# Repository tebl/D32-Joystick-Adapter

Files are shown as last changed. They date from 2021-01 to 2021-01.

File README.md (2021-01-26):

# D32 Joystick Adapter
I don't have a joystick for any of my Dragon 32s, I actually have two of them - mostly because it's the little welsh machine that thought it could - then it actually did! Often mentioned as a copy of the more successful american, but from what I can see - both of them seem to be a rather straight-forward implementation of a Motorola reference design from the same period. Where I live the computer didn't see much success until after its actual demise, the reason being that they became available at a very low price of *a freaking lot of money* (I was very young at a time, so anything that wasn't, well, a small stack of coins was still a lot to me).

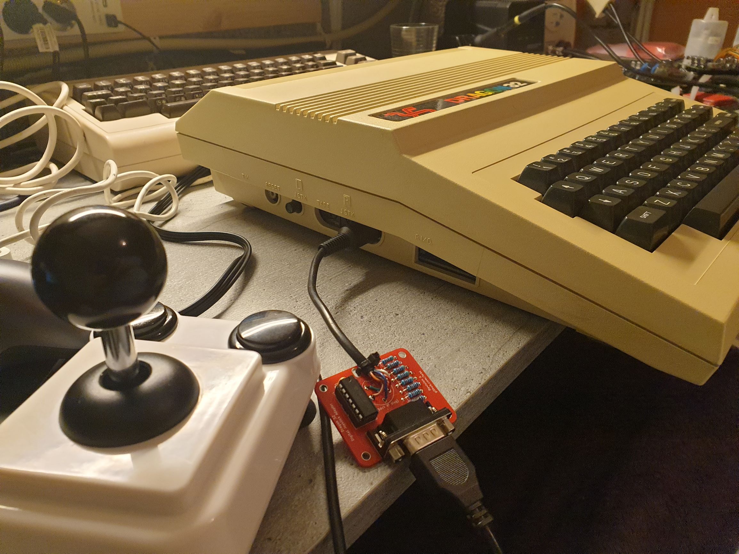
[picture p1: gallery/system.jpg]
Dragon 32


What I don't have however, is a working joystick for any of them. I can't buy one, mainly because according to someone very close to me - I appearantly have enough stuff! So I need to make some more - *all* by myself - *all by myself* (cue the music). Actually, I just searched around for a solution and with the power of Googles search engine at my fingertips - I copied the one from [vrai.net](http://vrai.net/retro/?p=112) and designed a PCB around it.

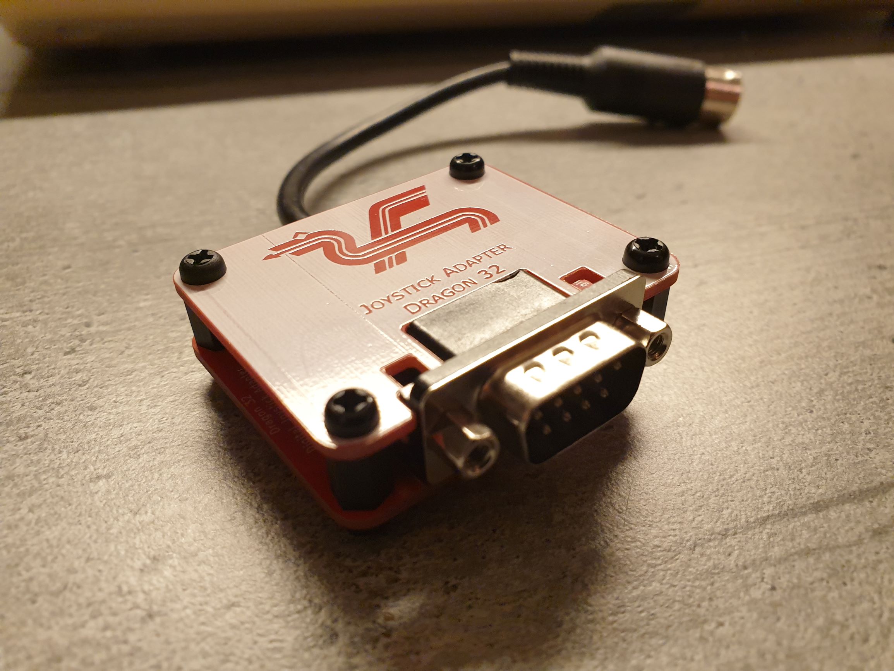
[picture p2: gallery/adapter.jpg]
D32 Joystick Adapter


Anyway - I'm rambling again, but for those just tuning into the workings of my basement laboratory - this project is about making an adapter so standard Atari 9-pin joysticks can be used with the Dragon 32 (also sold as the Tano Dragon in America) and Dragon 64 computers. In theory it could work for the TRS-80 Colour Computer (CoCo), but I don't have one - so until the day someone just gives me one, I can't test it. The finished project, including an optional faceplate can be seen above.

- [1> BOM](#1-bom)
  - [1.1>D32 Joystick Adapter](#11-d32-joystick-adapter)
  - [1.2> D32 Joystick Adapter (Faceplate)](#12-d32-joystick-adapter-faceplate)
- [2> Building the D32 Joystick Adapter](#2-building-the-d32-joystick-adapter)
  - [2.1> Testing it out](#21-testing-it-out)

# 1> BOM
This is the list of parts that you'd need in order to construct a D32 Joystick Adapter, most if not all should be readily available from your friendly neighbourhood electronics store if you should happen to have one available to you. For me, that means ebay since those kind of stores disappeared in the 80s around here - your mileage may wary (and so may the actual friendliness).

I've separated the parts belonging to the actual module into section 1.1, the faceplate is strictly optional and has no active components - I'm just having fun making these, so unless you want one you don't really need the components listed.

## 1.1> D32 Joystick Adapter
| Reference | Item | Count | Order  |
| --- | --- | ----- | --- |
| D32 Joystick Adapter PCB  | Fabricate using Gerber files | 1 | [PCBWay](https://www.pcbway.com/project/shareproject/D32_Joystick_Adapter.html) |
| J1 * | Male 240° connector and 5-core wire | 1 | |
| J2 | Male DB9 right-angle connector | 1 | |
| JP1 ** | 1x2 pin right-angle header and jumper | 1 | |
| R1,R3,R5,R7 | 10k Ohm resistor | 4 | |
| R2,R4,R6,R8 | 47k Ohm resistor | 4 | |
| U1 | CD4066 (DIP-14) | 1 | |

*) Note that this isn't actually a PCB-component, you're supposed to solder the male connector at the other end of the cable. One cheap source of these cables is either purchasing a cheap RS232 cable and cutting off both ends. Use a cable tie as strain relief.

**) This was added so that VCC could be removed from the cable if needed, the *C64 JoyKEY* when including the Arduino drags down the line a bit too much. If you only intend to use regular Atari-style joysticks, feel free to install a piece of wire shorting this instead.

## 1.2> D32 Joystick Adapter (Faceplate)
| Reference | Item | Count | Order  |
| --- | --- | ----- | --- |
| Faceplate A1 (PCB) * | Fabricate using Gerber files | 1 | [PCBWay](https://www.pcbway.com/project/shareproject/D32_Joystick_Adapter__Faceplate_.html) |
| Faceplate A2 (PCB) * | Fabricate using Gerber files | 1 | [PCBWay](https://www.pcbway.com/project/shareproject/D32_Joystick_Adapter__Faceplate_A2_.html) |
| Mounting ** | M3x8mm Nylon Hex standoff | 4 | |
| | M3x6mm nylon screw | 4 | |

*) The A1 and A2 faceplates serve the same function, so you will only need one of them. The A1 faceplate is the Dragon-themed one, A2 has something that should have a larger appeal to our American friends with access to a RadioShack TRS-80 Colour Computer.

**) The suggested nylon standoff should be common values, if you have one of the cheap M3 nylon standoff kits sold on ebay and similar site - feel free to try out whichever works best for you. Keeping within the limits of the kit I'd use the 8mm standoffs, use screws on top and nuts on the underside (cut off the remainder of the screw poking through).

# 2> Building the D32 Joystick Adapter
Building the *D32 Joystick Adapter* should for the most part be an easy affair for most with access to a decent set of tools, burn-proof fingers and a deep-seeded interest in playing games on a Dragon 32 using an Atari-style joystick. Start by reading through the BOM above for a list of all parts required, order what you don't already have tucked into a drawer, chest or the back of the sofa cushions - wherever you keep yours. Everything? Read on for the exciting conclusion to project *"clicky joy with the Dragon 32"*.

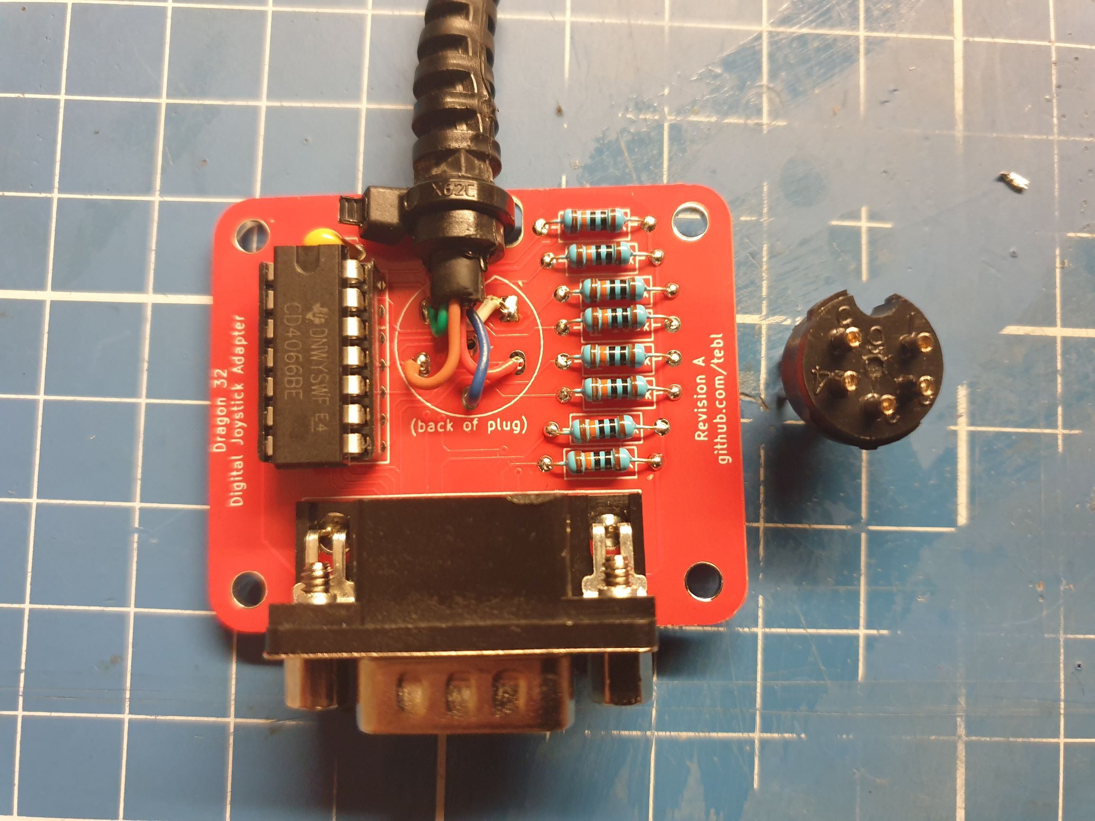
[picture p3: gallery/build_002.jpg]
Build 002


Still here? Excellent.

As pictured above, where I've already done most of the work you can see the finished module. There are many roads to getting there, but the easiest is starting with the resistors - solder them in according to the values printed. Install a 14-pin socket for U1 as everyone hates removing non-functional chips, which is something that's a regularly common affair when ordering things from the non-professional electronic component vendors - they're usually cheaper than regular chips though.

At this point you could install the DB9-connector if you wanted, but I recommend paying attention to the cable install instead - the one with a picture of a DIN-plug on. As long as you've got a cable with enough cores and the ability to tell the wires apart, just pick a colour for each and solder them into place (I'm assuming there isn't a connector on the other end at this point). Use the two larger holes above to zip-tie the cable into place, this ensures that the cable doesn't come undone in the next few days.

Note that the pins on the PCB has been numbered for you, the connector will also have something similar on it. **BEFORE** continuing though, thread the sleeve onto the cable - failiure to do so means you'll have to desolder something tonight (might be either end of the cable). Use the PCB directions on the topside, back of plug view and match the coloured wires to the correct number. Use the numbering on the underside if you're attempting to match it to something that already has the correct connector attached, such as when upcycling the cable from a non-functioning joystick.

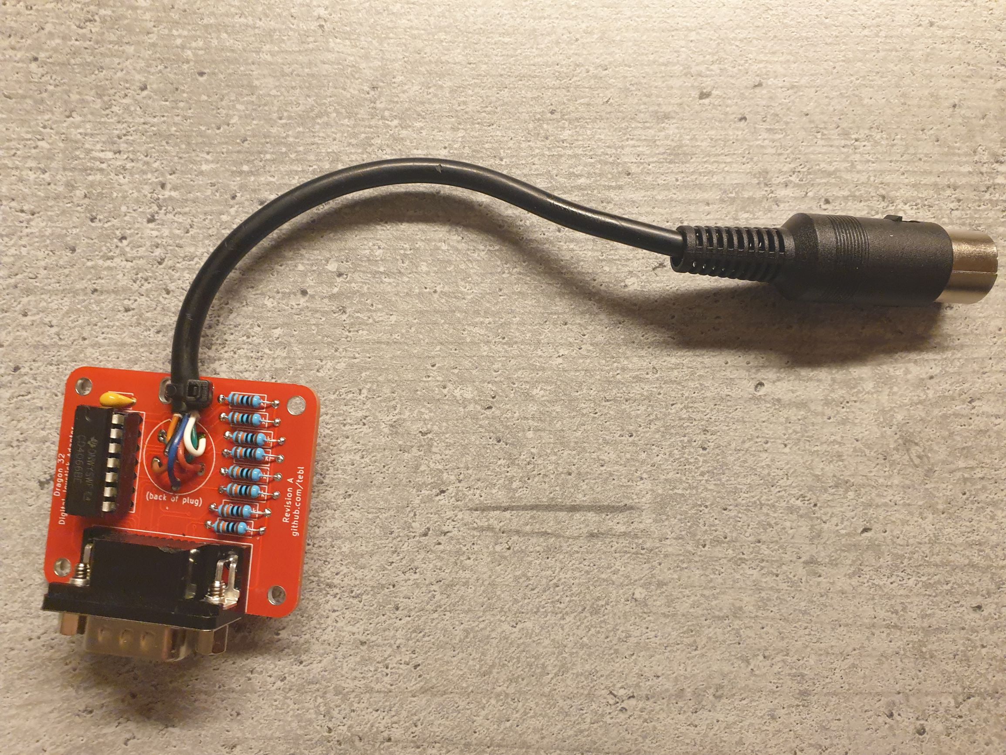
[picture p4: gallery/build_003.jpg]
Build 003


It is my hope that everything'll work out as it should, but before you connect it up to a Dragon 32 I highly recommend that you check for any direct shorts on the power side of things - this is easily done by checking for a lack of contiuity between U1 pins 7 and 14. If you opted for a faceplate, just screw it on using the standoffs listed in the BOM.

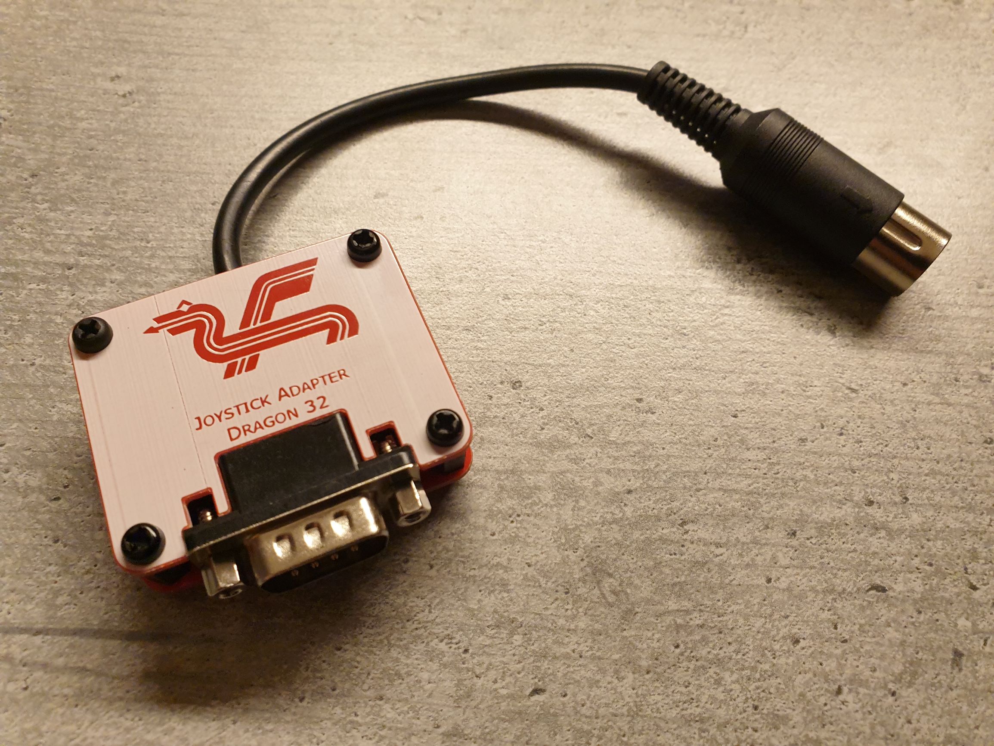
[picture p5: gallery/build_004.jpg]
Build 004


That should be every bit of knowledge I'm able to impart on you this evening, excuse the mistakes and exceptionally bad puns!

## 2.1> Testing it out
Going back to the hope we had in the building section, we now resort to my less than plug-and-pray way of attacking the project. Plug it into the computer, plug an Atari-style joystick into the **right** joystick - because why not do the right one? I got lazy on the script I borrowed from [dragon32forever](https://dragon32forever.wordpress.com/dragon-bytes/joysticks/), that's why. I've included it in the repository under [software](https://github.com/tebl/D32-Joystick-Adapter/tree/main/software), don't bother breaking out a DragonDrive or DragonMMC to load the thing - it is a tiny thing so just type it in.

Here's the next part: RUN

The script should flicker the screen a lot, but between the flickering you should see some numbers for the X- and Y-axis. It should display a number between 0 and 63, when pushing the joystick in all the ways it should jump between the extremes. When not pushing anything it should center somewhere along the middle (around 30).

I found that my [C64 JoyKEY](https://github.com/tebl/C64-JoyKEY) with an Arduino installed pulls the VCC-line too far down (my max value didn't go above 40) so it didn't work properly unless the VCC_EN jumper is removed, the Dragon 32 simply wasn't meant to power an Arduino and a bunch of LEDs via the joystick port - most common Atari-style joysticks with a sensible amount of circuitry should work properly.

Now go play some games, I recommend starting with either *Rommel's Revenge* or *Donkey King* - both worked pretty great for the 5 minutes I spent playing them. That's a pretty good statistic, I just prefer building things these days!

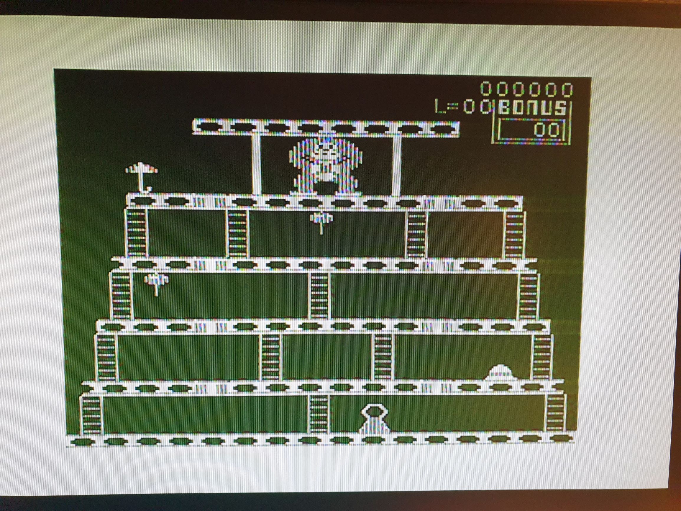
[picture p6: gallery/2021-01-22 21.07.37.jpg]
Donkey King


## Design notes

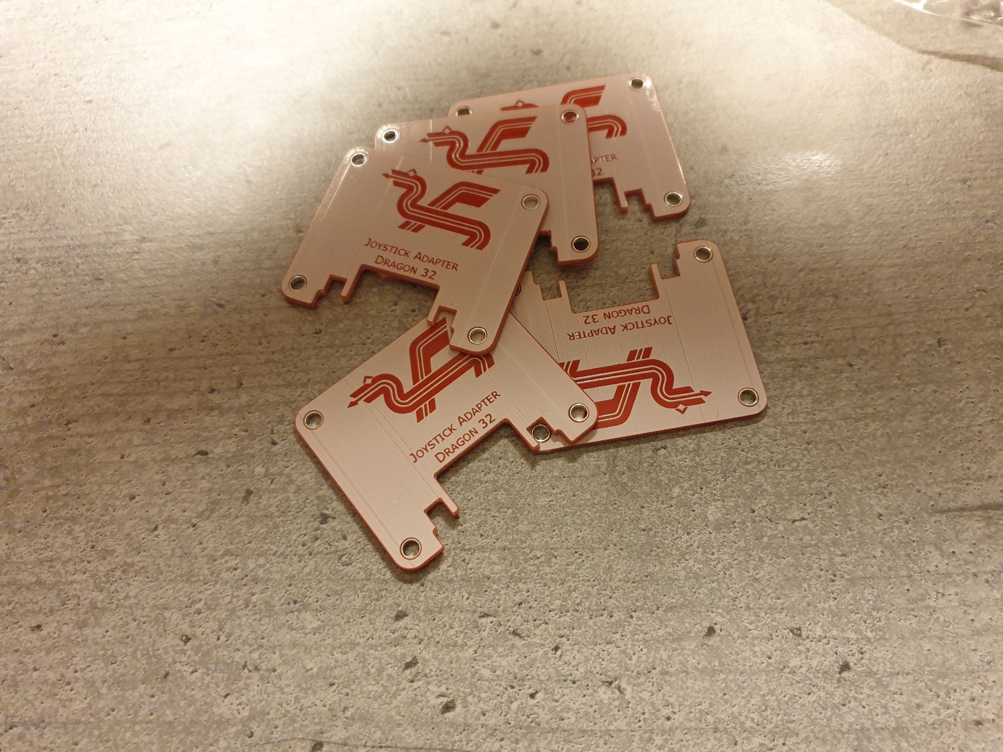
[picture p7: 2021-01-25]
gallery/faceplates.jpg

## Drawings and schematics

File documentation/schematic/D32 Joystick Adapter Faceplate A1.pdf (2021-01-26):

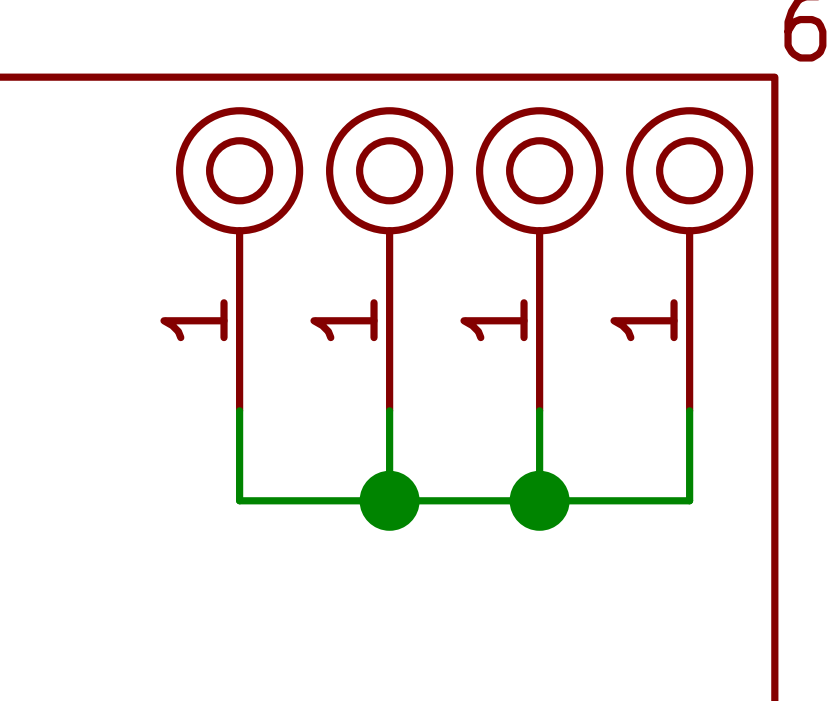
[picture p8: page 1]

File: D32 Joystick Adapter Faceplate A1.sch Sheet: / Faceplate for the D32 Joystick Adapter.

Id: 1/1 Title: D32 Joystick Adapter (Faceplate)

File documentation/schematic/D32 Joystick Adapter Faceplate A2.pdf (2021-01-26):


File: D32 Joystick Adapter Faceplate A2.sch Sheet: / Faceplate for the D32 Joystick Adapter.

Id: 1/1 Title: D32 Joystick Adapter (Faceplate)

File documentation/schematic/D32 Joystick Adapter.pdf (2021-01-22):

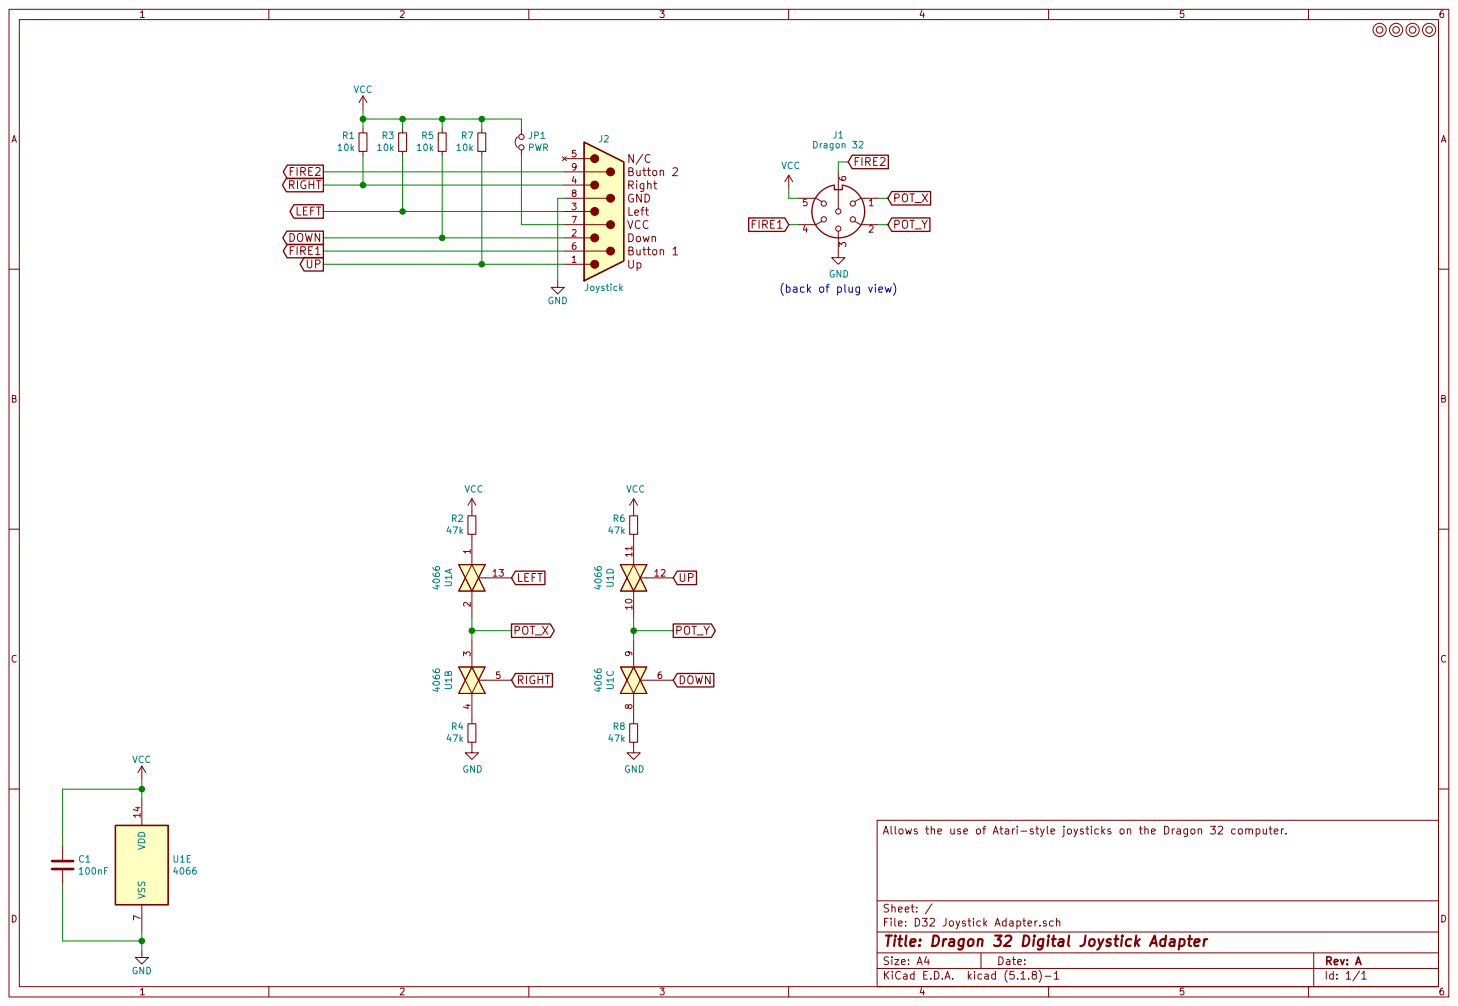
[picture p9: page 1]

(back of plug view)

File: D32 Joystick Adapter.sch Sheet: / Allows the use of Atari-style joysticks on the Dragon 32 computer.

Id: 1/1 Title: Dragon 32 Digital Joystick Adapter

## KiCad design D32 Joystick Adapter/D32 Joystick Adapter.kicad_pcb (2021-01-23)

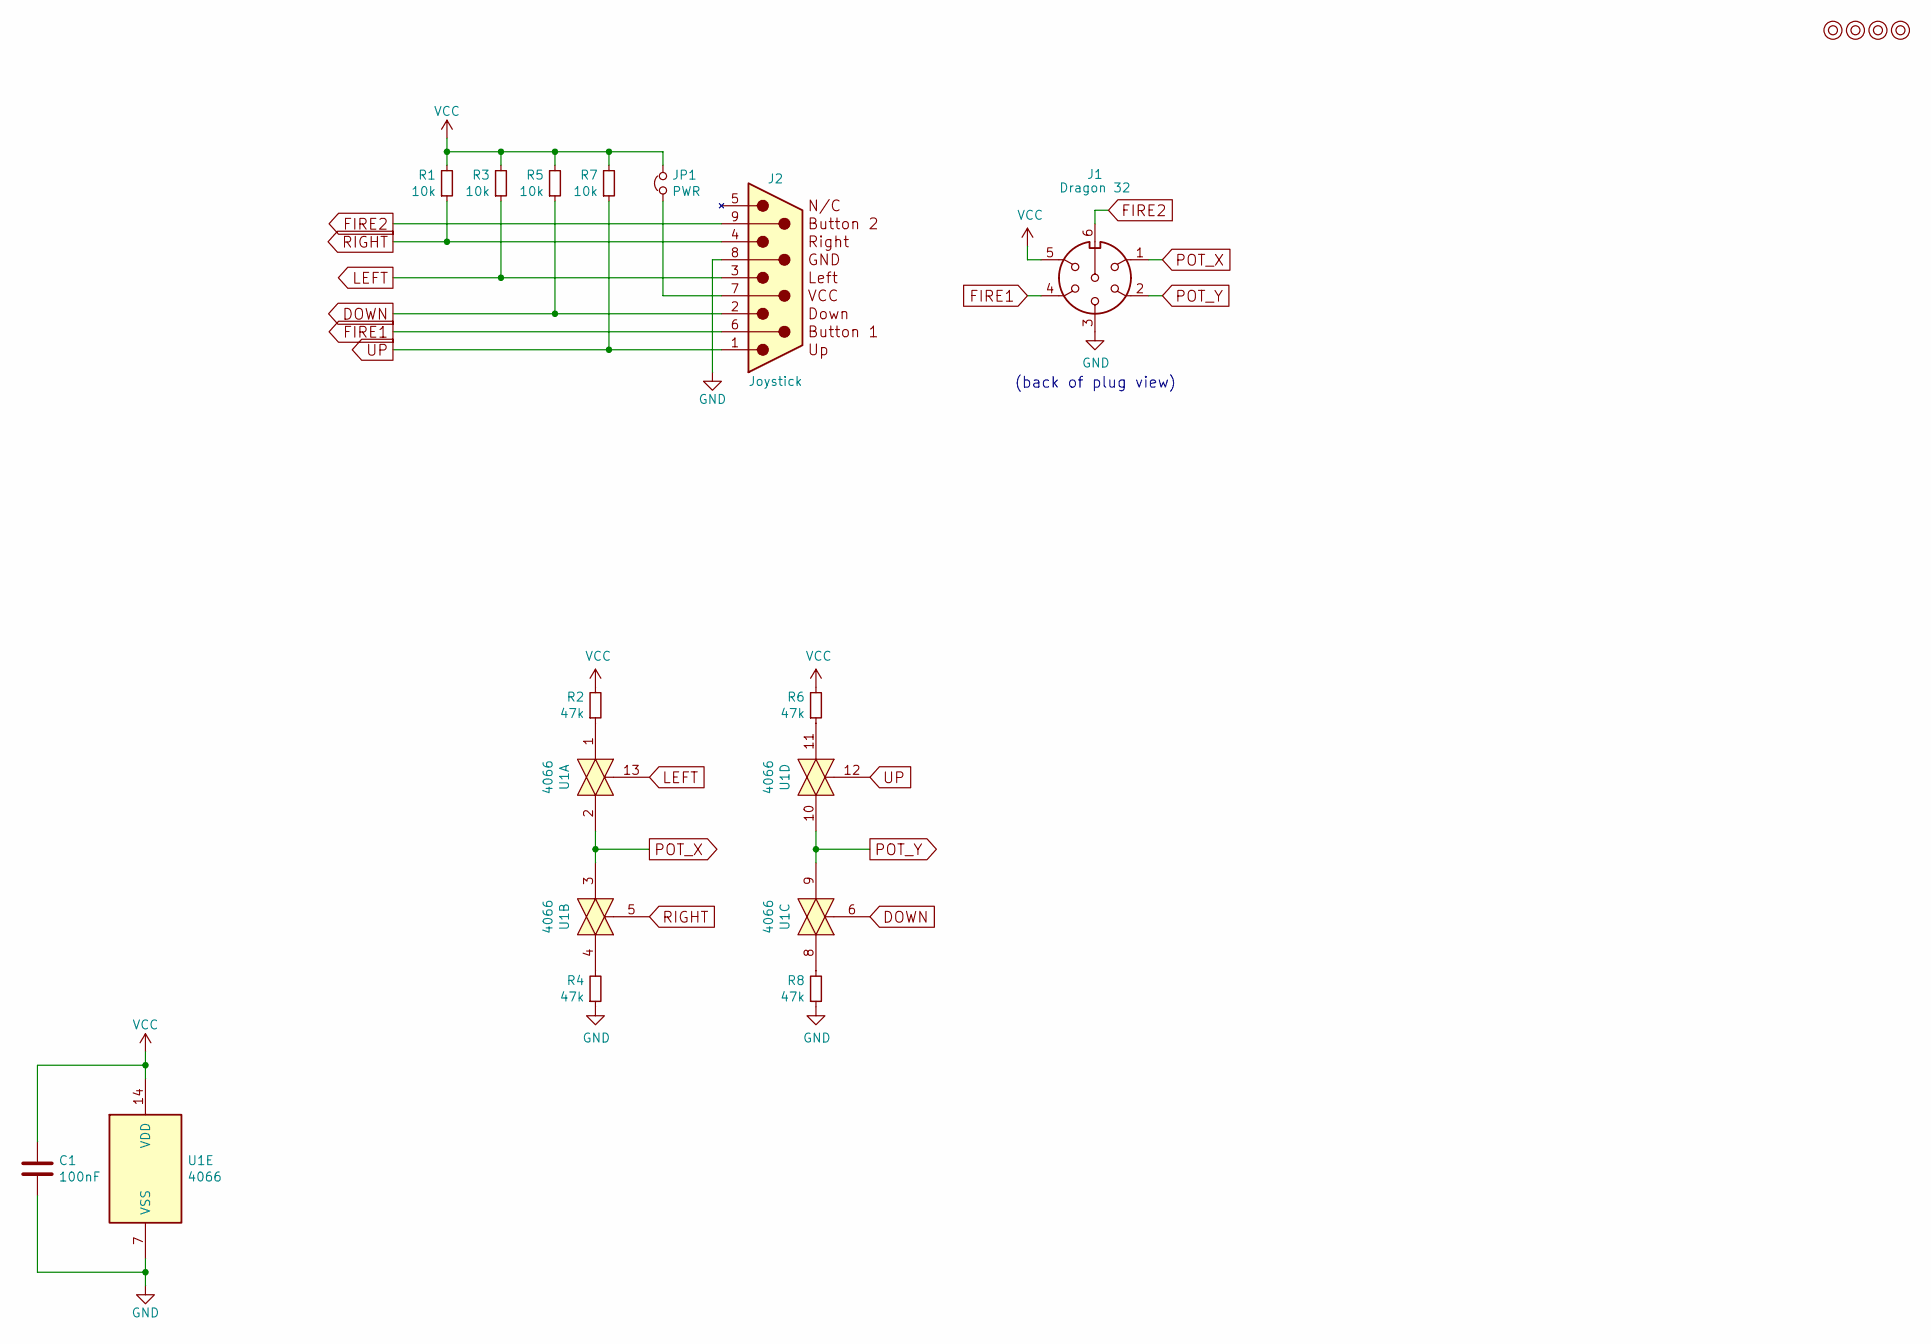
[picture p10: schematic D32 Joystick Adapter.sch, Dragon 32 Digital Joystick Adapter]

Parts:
C1: 100nF; C_Disc_D4.7mm_W2.5mm_P5.00mm
J1: Dragon 32; OUTPUT_ZIP
J2: Joystick; DSUB-9_Male_Horizontal_P2.77x2.84mm_EdgePinOffset7.70mm_Hou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
JP1: PWR; PinHeader_1x02_P2.54mm_Horizontal
M1, M2, M3, M4: Mounting; M3_pin
R1, R3, R5, R7: 10k; R_Axial_DIN0207_L6.3mm_D2.5mm_P10.16mm_Horizontal
R2, R4, R6, R8: 47k; R_Axial_DIN0207_L6.3mm_D2.5mm_P10.16mm_Horizontal
U1: 4066; DIP-14_W7.62mm_Socket_LongPads

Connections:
DOWN: J2.2, R5.1, U1.6
FIRE1: J1.4, J2.6
FIRE2: J1.6, J2.9
GND: C1.2, J1.3 (GND), J2.8 (GND), R4.1, R8.1, U1.7 (VSS)
LEFT: J2.3, R3.1, U1.13
unnamed: J2.7 (VCC), JP1.1
unnamed: R2.1, U1.1
unnamed: R4.2, U1.4
unnamed: R6.1, U1.11
unnamed: R8.2, U1.8
POT_X: J1.1, U1.2, U1.3
POT_Y: J1.2, U1.9, U1.10
RIGHT: J2.4, R1.1, U1.5
UP: J2.1, R7.1, U1.12
VCC: C1.1, J1.5 (VCC), JP1.2, R1.2, R2.2, R3.2, R5.2, R6.2, R7.2, U1.14 (VDD)

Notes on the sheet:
(back of plug view)

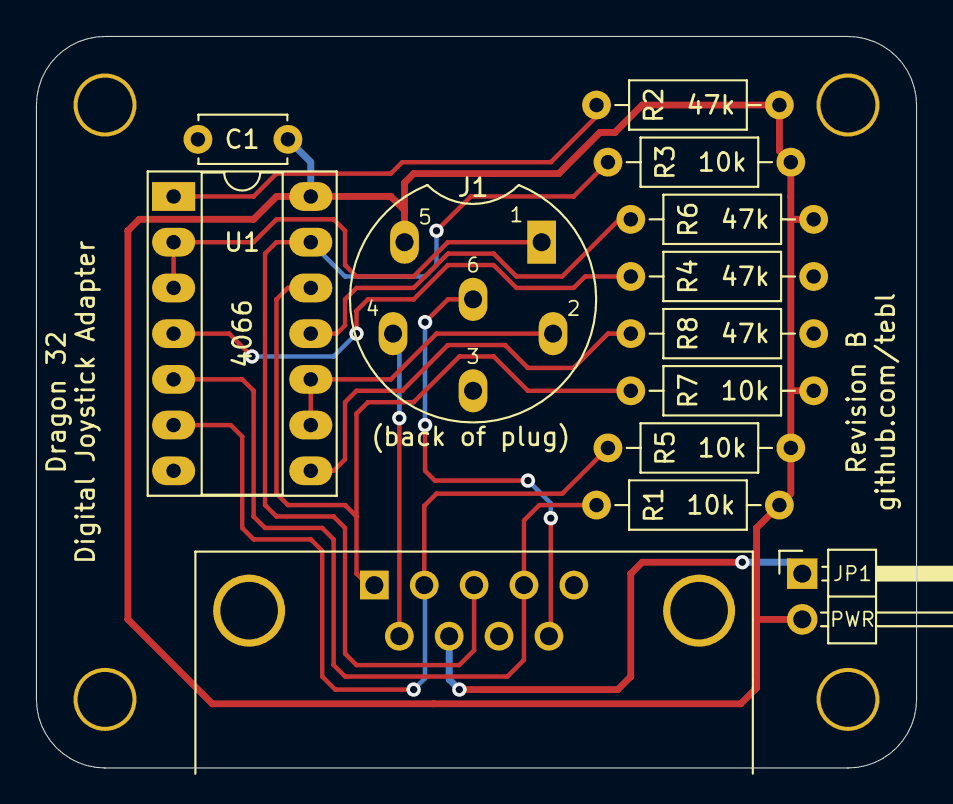
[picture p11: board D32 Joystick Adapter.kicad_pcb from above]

Board: 2 copper layers, 48.9 x 40.6 mm, 17 parts (0 on the bottom side), 15 nets.

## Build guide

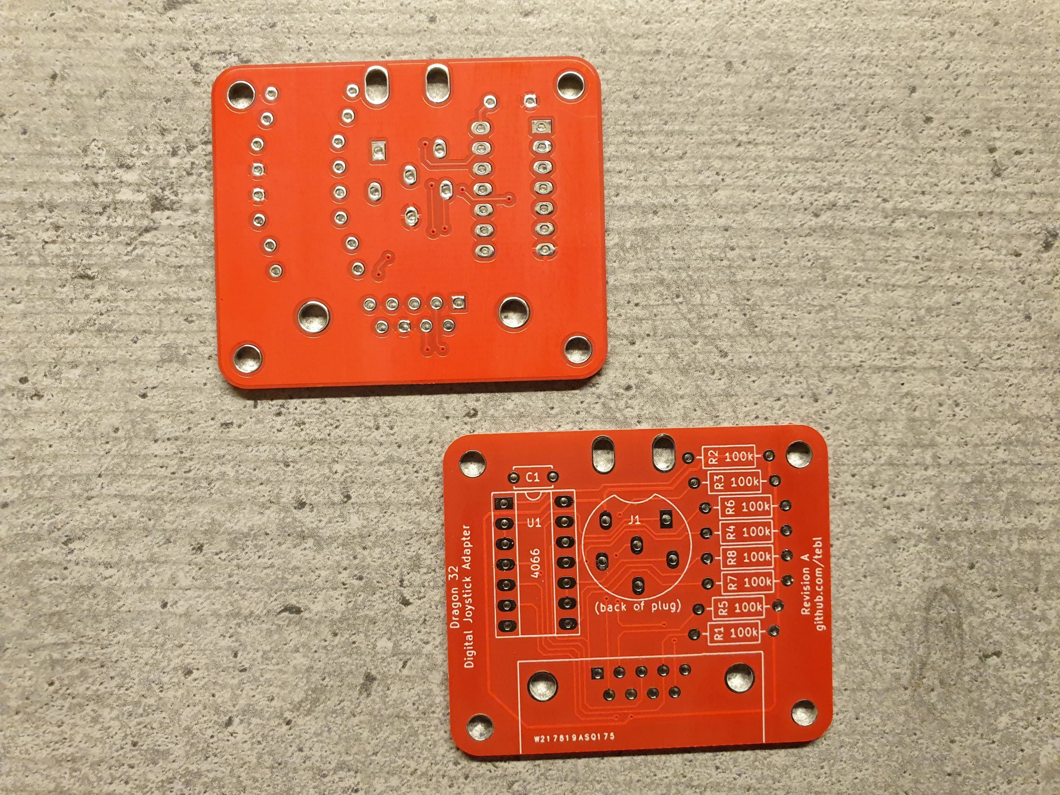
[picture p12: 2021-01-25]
gallery/build_001.jpg

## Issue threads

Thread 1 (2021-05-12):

c1 value

indiosse, 2021-05-12:
is that a capacitor at C1 on the board , what is its value ??

tebl, 2021-05-12:
It's 100nF (0.1uF), it has a pin spacing of 5mm.

ons. 12. mai 2021, 19:04 skrev indiosse ***@***.***>:

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

indiosse, 2021-05-12:
Hi

Can I ask what is voltage of the capacitor, also is the purpose just so you can use these lower resistance values ?
As I think usually people use at least 100k resistors

Sent from Mail<https://go.microsoft.com/fwlink/?LinkId=550986> for Windows 10

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

tebl, 2021-05-12:
The purpose of it is just to keep the power to the IC from fluctuating too
much. The resistor values were just to pick something, 10k seemed to work
well enough. I think you could substitute 100k for the 47k ones, it is the
ratio that matters as long as power consumption is kept below what the port
supports.

ons. 12. mai 2021, 21:17 skrev indiosse ***@***.***>:

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

indiosse, 2021-05-12:
Interesting so is the capacitor just an option, not necessary at all for the converter to work?

I

Sent from Mail<https://go.microsoft.com/fwlink/?LinkId=550986> for Windows 10

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

tebl, 2021-05-12:
It's just good practice to include one, if only to rule it put as a
potential issue. More than likely it'd work fine as long as the cable
between it and the computer isn't on the longer side (10-15cm would
probably be fine).

ons. 12. mai 2021, 21:26 skrev indiosse ***@***.***>:

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

Closed 2022-10-03.

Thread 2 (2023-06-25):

Built a Rev B joystick adapter but I am getting no signals from it.

Verault, 2023-06-25:
I built one of your Rev B joystick adapters and cant get any of my joysticks to show a signal through it on any came cart I plug in.
https://photos.app.goo.gl/vmTawGi84eFRXMJB8

Granted I own a tandy color computer. Everything I read online says the joysticks are pin for pin compatible. Following your photos and information I omitted pin 6 on the joystick adapter (which is for secondary fire button only correct?)

Maybe I am uncertain about the jp1 power jumper? Am I supposed to have this jumpered or connect an external power source? Would love to know what I did wrong on this build. Thanks

Verault, 2023-06-26:
Thank you. I will try my stock of 4066 ics and the test script and report back.

tebl, 2023-06-26:
JP1 is just in case the joystick has an autofire circuit that require power, most should work without it.

Verault, 2023-06-26:
Ok I think I made some progress. First off I ran the basic script and it it showing X and Y activity on all of my 4066 (I have 10). However the basic script it blinking strangely. At the top of the program There is the X: line which blinks, next line down is the Y: line which blinks very fast.
Below that is the F: line which blinks so much I can not really see it at all. I get a glimpse of a value of 0 very briefly but that is it? Is this a PAL vs NTSC timing issue?

So It seems to me as if the fire button is not making a signal. The soldering is good I can trace the #4 pin from the pcb to the din connector pin.  All the game carts I put in say press a button to play and they dont play as the fire button does not seem to work (I am guessing). I have tried 3 different known good joysticks. One with autofire, another a typical atari 2600 style joystick, and a commodore 64 joystick. They all behave the same.

tebl, 2023-06-26:
The flickering is probably cls command running, then immediately printing.
It's a bit of an eye strain, but it was meant to be quick and fast to type
in.

I linked an article below, it has a different version of the script and may
work better on a Tandy (mine was for a Dragon as those are what I have).

https://homecomputerguy.de/en/2022/01/02/joystick-adapter-for-tandy-color-computer/

man. 26. jun. 2023, 18:45 skrev Verault ***@***.***>:

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

Verault, 2023-06-29:
Thanks for the link. I tried the program and it is indeed easier to look at. I also hooked up pin 6 with a bodge wire (in the thinking that maybe the Tandy COCO series is using fire2 instead of fire1 and just knowing all pins are connected.

With that said I am getting the same results. I have X and Y but the fire button(s) dont register anything on known working joysticks.

Ill side on the thinking that maybe I did something wrong in building this adapter and build a second one to see if I get the same results. This is very odd indeed.

Verault, 2023-07-17:
Ok. After alot of frustration and troubleshooting I was able to resolve this problem.
In a nutshell I for some reason swapped pins 4 and 5 from the joystick adapter to the Din cable.

IT now tests and works great. I will close out the issue but I just wanted to let you know this adapter in fact works great on the Tandy TRS-80 Coco 1 and Coco 2.  I dont own a Coco 3 but I suspect it works fine on those machines. So you can update this repository for future builders. I just finished up testing on my Coco 1 and 2 and it works perfectly.

Thank you!

tebl, 2023-07-18:
Glad to hear that you got it working. Sometimes the journry to the answer
is worth just as much as the answer, also... you get to play games with it
:-)

tir. 18. jul. 2023, 01:41 skrev Verault ***@***.***>:

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

Closed 2023-07-18.

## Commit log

2021-01-12 Schematic done
    [D32 Joystick Adapter.kicad_pcb, D32 Joystick Adapter.sch]
2021-01-13 Layout done
    [D32 Joystick Adapter-B_Cu.gbl, D32 Joystick Adapter-B_Mask.gbs, D32 Joystick Adapter-B_Paste.gbp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]
2021-01-13 Faceplate logo
    [D32 Joystick Adapter.kicad_pcb]
2021-01-17 Add faceplate
    [D32 Joystick Adapter Faceplate A1-B_Cu.gbl, D32 Joystick Adapter Faceplate A1-B_Mask.gbs, D32 Joystick Adapter Faceplate A1-B_Paste.gbp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]
2021-01-19 Changed faceplate cutout
    [D32 Joystick Adapter Faceplate A1-B_Cu.gbl, D32 Joystick Adapter Faceplate A1-B_Mask.gbs, D32 Joystick Adapter Faceplate A1-B_Paste.gbp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]
2021-01-20 Added pinout to silkscreen
    [D32 Joystick Adapter Faceplate A1.kicad_pcb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]
2021-01-22 Added power jumper and changed resistor values
    [D32 Joystick Adapter-B_Cu.gbl, D32 Joystick Adapter-B_Mask.gbs, D32 Joystick Adapter-B_Paste.gbp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]
2021-01-23 Added LICENSE text to PCB
    [D32 Joystick Adapter-B_Cu.gbl, D32 Joystick Adapter-B_Mask.gbs, D32 Joystick Adapter-B_Paste.gbp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]
2021-01-26 Slightly more cutout space
    [D32 Joystick Adapter Faceplate A1-B_Cu.gbl, D32 Joystick Adapter Faceplate A1-B_Mask.gbs, D32 Joystick Adapter Faceplate A1-B_Paste.gbp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]
2021-01-26 CoCo faceplate
    [D32 Joystick Adapter Faceplate A2-B_Cu.gbl, D32 Joystick Adapter Faceplate A2-B_Mask.gbs, D32 Joystick Adapter Faceplate A2-B_Paste.gbp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]

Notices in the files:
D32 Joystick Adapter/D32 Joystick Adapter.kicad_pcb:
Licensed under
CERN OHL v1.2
